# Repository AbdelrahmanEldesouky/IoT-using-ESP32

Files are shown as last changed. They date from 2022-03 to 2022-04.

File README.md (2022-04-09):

# IoT using ESP32 for Home Control 

## Software 

Programming nodeMCU-32S using [Arduino code](Home_Control/Software/HomeControl/HomeControl.ino) to connect with io.adafruit platform using MQTT protocol 

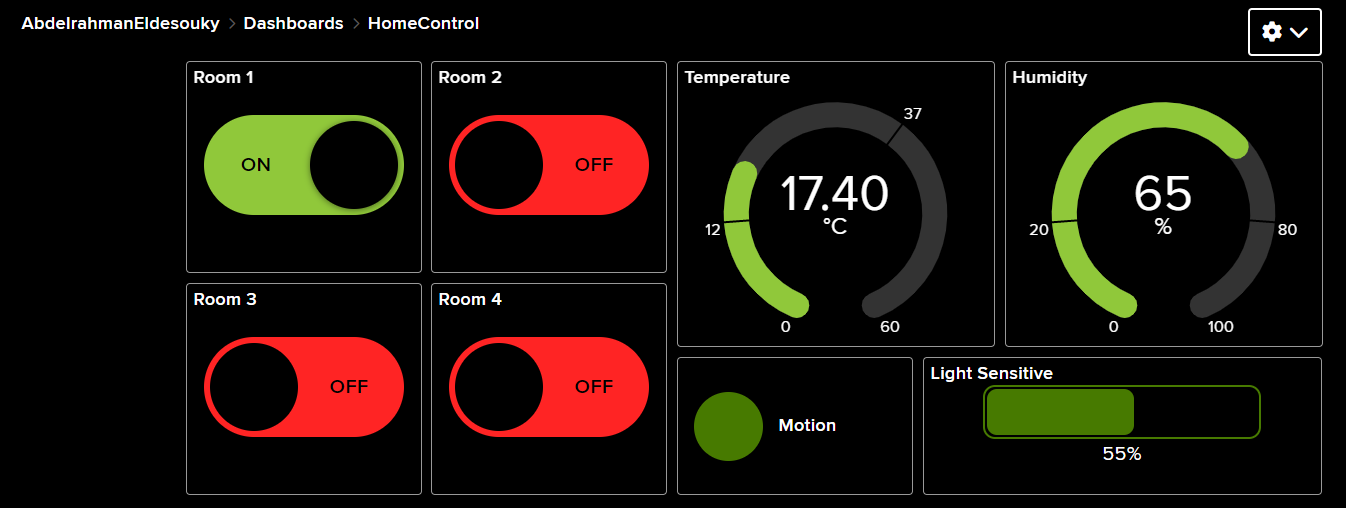
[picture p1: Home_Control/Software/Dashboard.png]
Dashboard


## Hardware

### Component 

1. nodeMCU-ESP32S
2. BT139 
3. MOC3022m 
4. PIR Sensor
5. DHT11 
6. LDR 

Check [data sheet](Home_Control/Hardware/Datasheet) for used components. 

### Schematic 

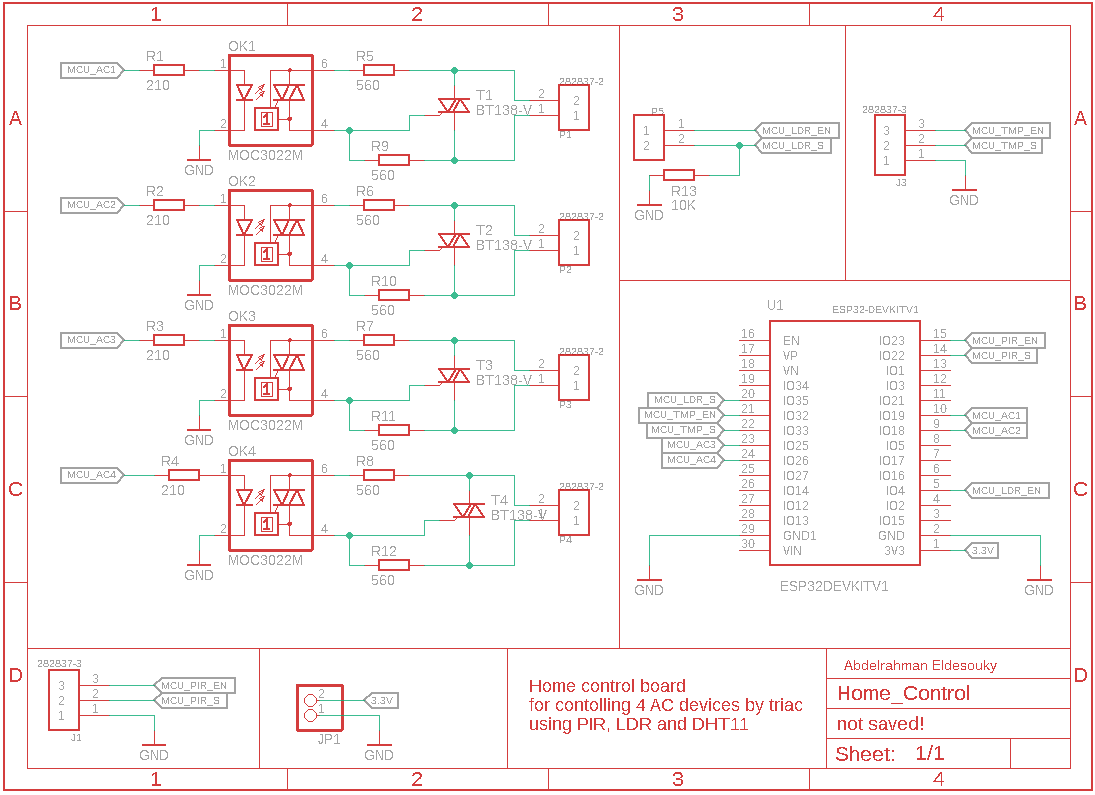
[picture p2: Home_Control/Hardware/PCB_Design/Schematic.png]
Schematic


### Layout 

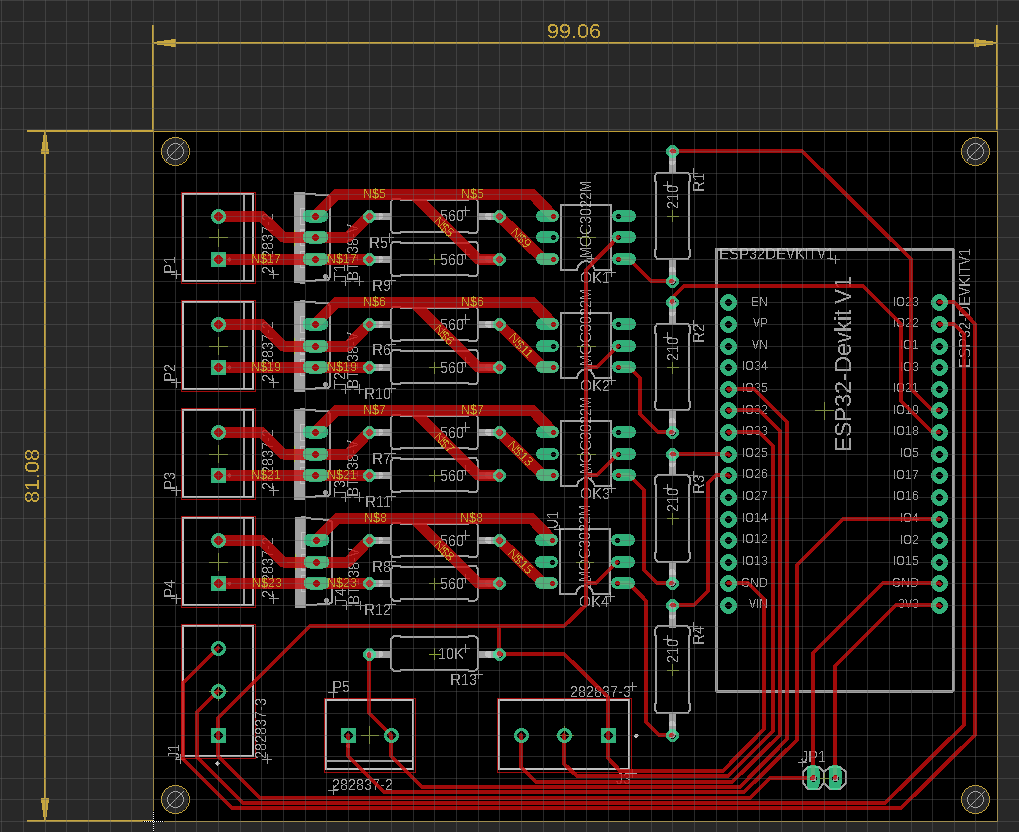
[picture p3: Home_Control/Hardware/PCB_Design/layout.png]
layout


### Prototype

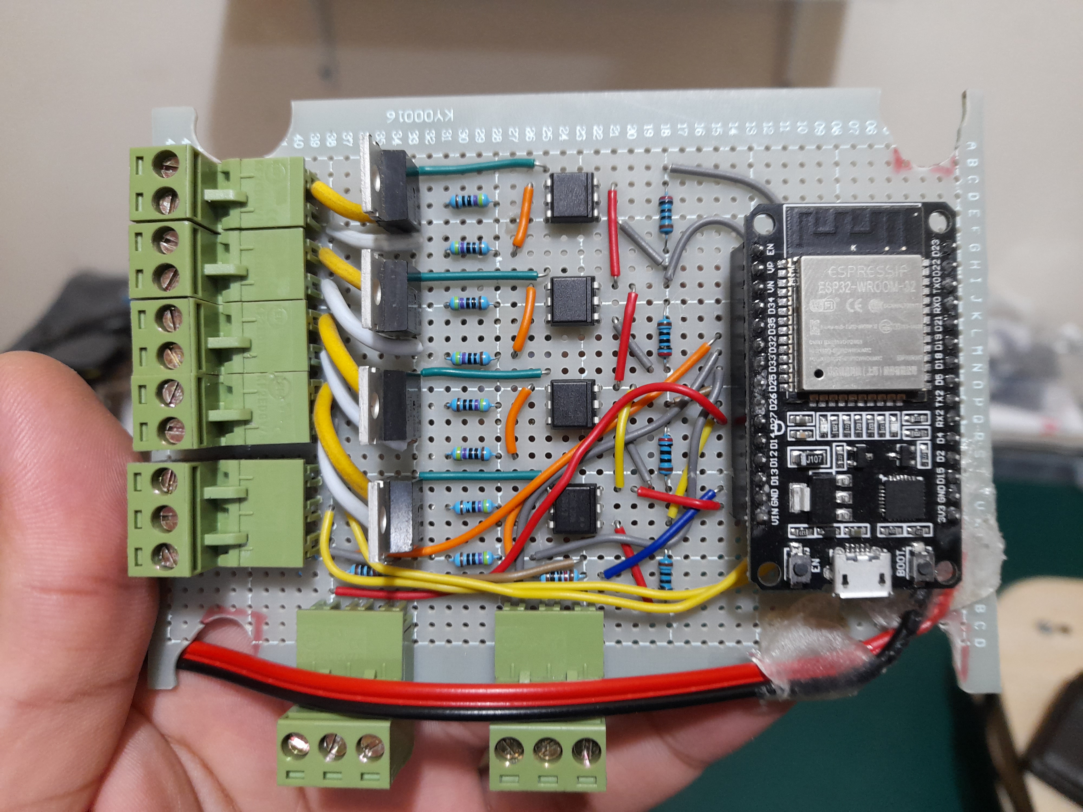
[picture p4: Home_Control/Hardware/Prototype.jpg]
Prototype


### PCB 3D View

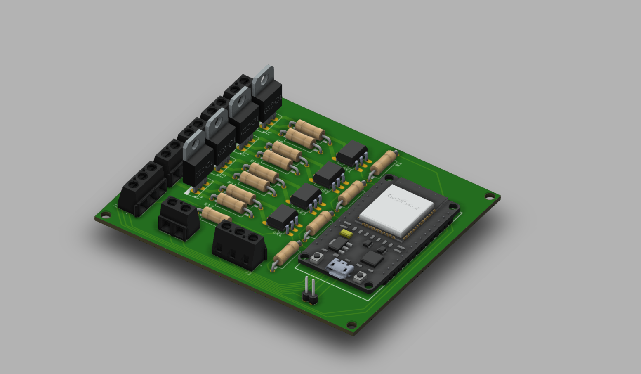
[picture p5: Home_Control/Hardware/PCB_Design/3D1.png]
3D#1


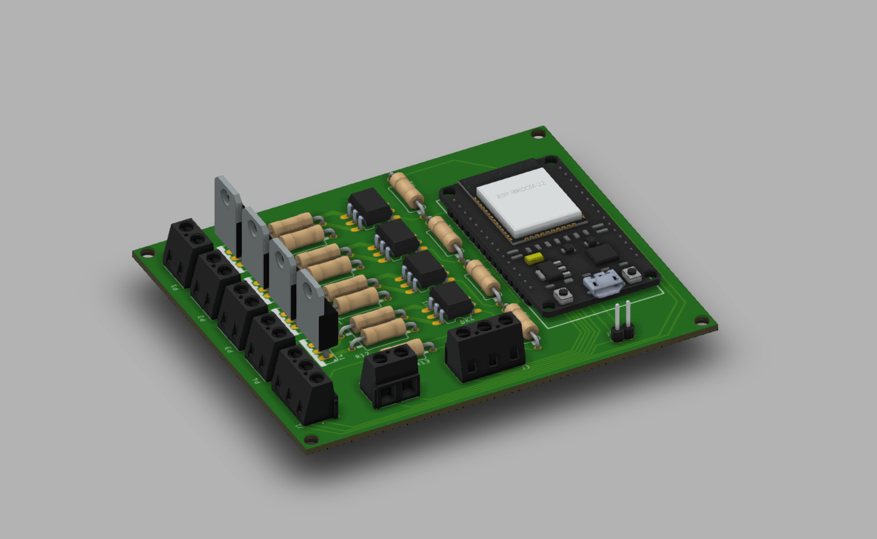
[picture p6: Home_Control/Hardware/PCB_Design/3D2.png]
3D#2


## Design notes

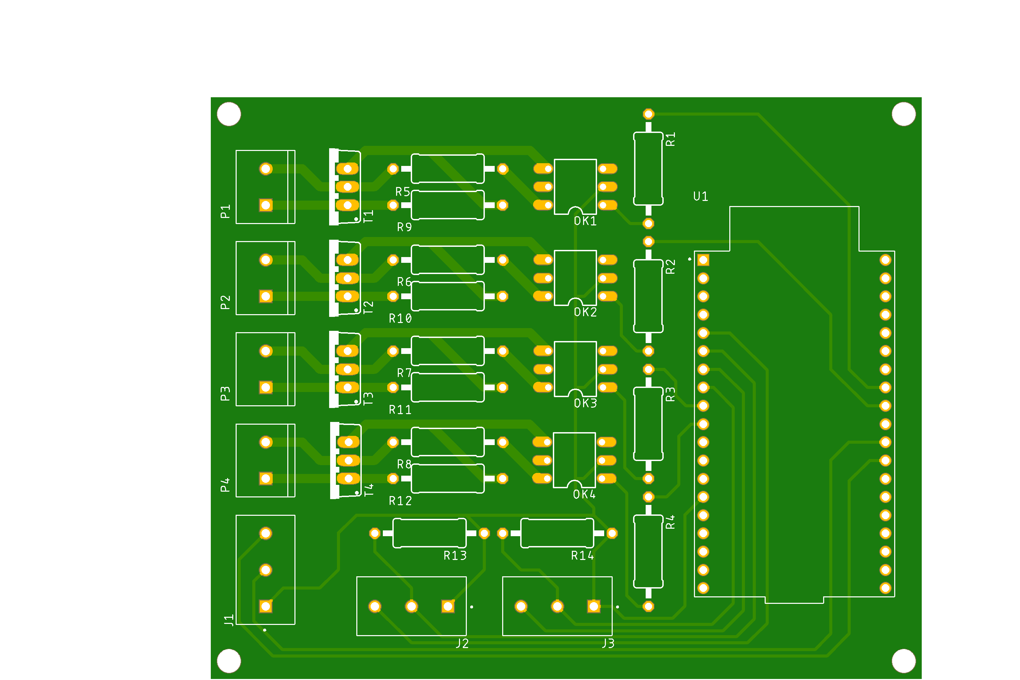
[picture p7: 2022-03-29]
Home_Control/Hardware/PCB_Design/Home_Control.png

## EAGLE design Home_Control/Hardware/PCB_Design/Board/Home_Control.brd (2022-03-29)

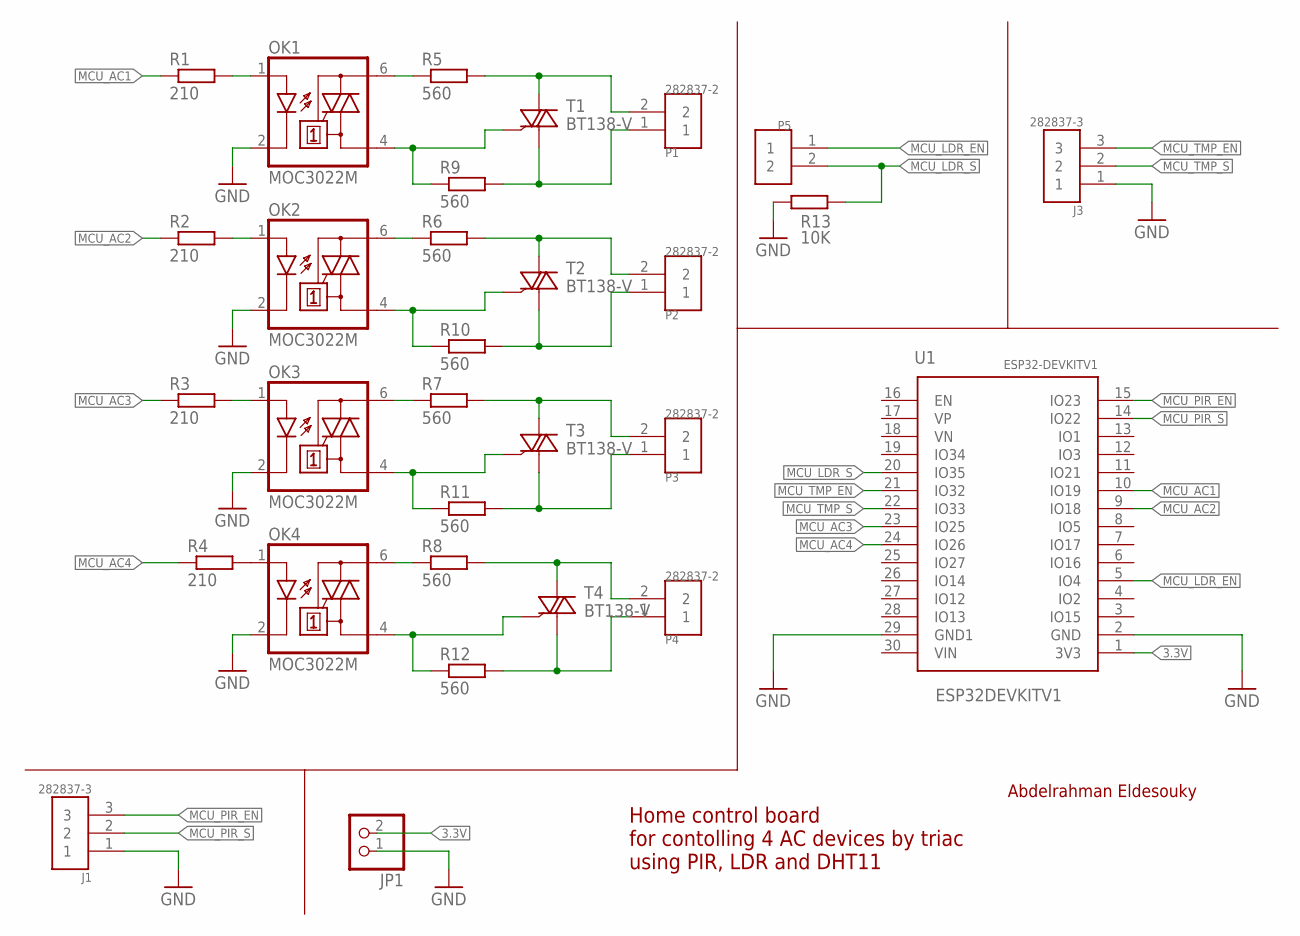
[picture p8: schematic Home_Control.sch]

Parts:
J1, J3: 282837-3; TE_282837-3
JP1: PINHD-1X2; 1X02
OK1, OK2, OK3, OK4: MOC3022M; DIL06
P1, P2, P3, P4, P5: 282837-2; TE_282837-2
R1, R2, R3, R4: 210; 0411/15
R5, R6, R7, R8, R9, R10, R11, R12: 560; 0411/15
R13: 10K; 0411/15
T1, T2, T3, T4: BT138-V; TO220BV
U1: ESP32DEVKITV1; ESP32-DEVKITV1

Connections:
3.3V: JP1.2, U1.1 (3V3)
GND: J1.1, J3.1, JP1.1, OK1.2 (C), OK2.2 (C), OK3.2 (C), OK4.2 (C), R13.1, U1.2 (GND), U1.29 (GND1)
MCU_AC1: R1.1, U1.10 (IO19)
MCU_AC2: R2.1, U1.9 (IO18)
MCU_AC3: R3.1, U1.23 (IO25)
MCU_AC4: R4.1, U1.24 (IO26)
MCU_LDR_EN: P5.1, U1.5 (IO4)
MCU_LDR_S: P5.2, R13.2, U1.20 (IO35)
MCU_PIR_EN: J1.3, U1.15 (IO23)
MCU_PIR_S: J1.2, U1.14 (IO22)
MCU_TMP_EN: J3.3, U1.21 (IO32)
MCU_TMP_S: J3.2, U1.22 (IO33)
unnamed: OK1.1 (A), R1.2
unnamed: OK2.1 (A), R2.2
unnamed: OK3.1 (A), R3.2
unnamed: OK4.1 (A), R4.2
unnamed: OK1.4 (A1), R9.1, T1.G
unnamed: OK2.4 (A1), R10.1, T2.G
unnamed: OK3.4 (A1), R11.1, T3.G
unnamed: OK4.4 (A1), R12.1, T4.G
unnamed: OK1.6 (A2), R5.1
unnamed: P1.2, R5.2, T1.T2 (A2)
unnamed: OK2.6 (A2), R6.1
unnamed: P2.2, R6.2, T2.T2 (A2)
unnamed: OK3.6 (A2), R7.1
unnamed: P3.2, R7.2, T3.T2 (A2)
unnamed: OK4.6 (A2), R8.1
unnamed: P4.2, R8.2, T4.T2 (A2)
unnamed: P1.1, R9.2, T1.T1 (A1)
unnamed: P2.1, R10.2, T2.T1 (A1)
unnamed: P3.1, R11.2, T3.T1 (A1)
unnamed: P4.1, R12.2, T4.T1 (A1)

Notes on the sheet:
Abdelrahman Eldesouky
Home control board for contolling 4 AC devices by triac using PIR, LDR and DHT11

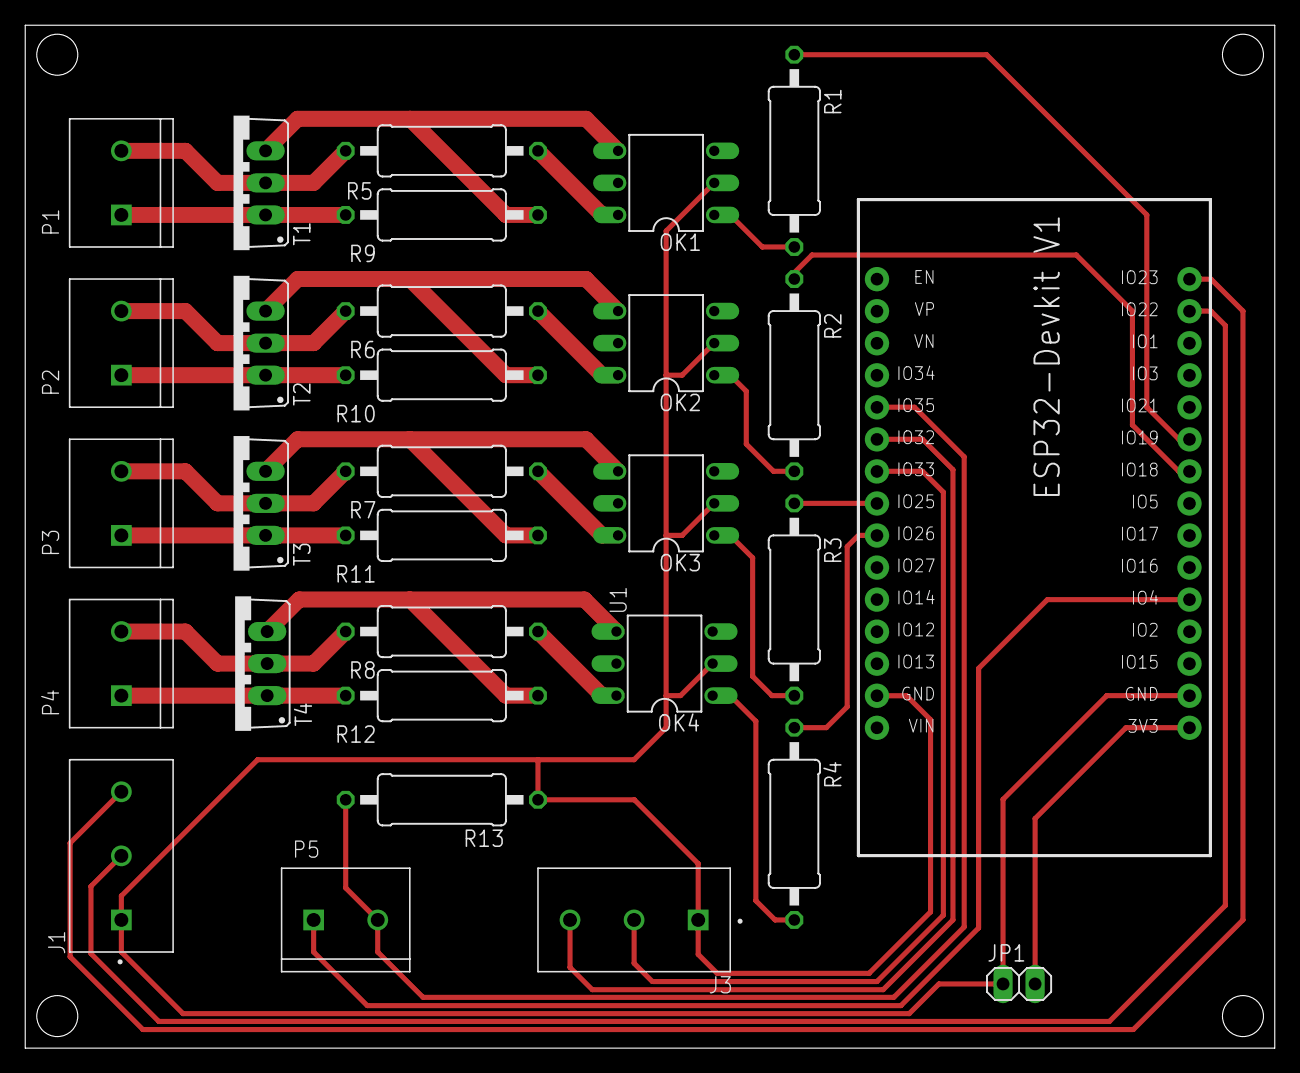
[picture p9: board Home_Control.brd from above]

Board: 2 copper layers, 99.0 x 81.1 mm, 30 parts (0 on the bottom side), 32 nets.

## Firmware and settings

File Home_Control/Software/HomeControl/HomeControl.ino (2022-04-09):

/************************ Include used library ************************/
#include <WiFi.h>
#include "Adafruit_MQTT.h"
#include "Adafruit_MQTT_Client.h"
#include "DHT.h"

/************************ wifi setup ************************/
#define WIFI_SSID       "Desoky"
#define WIFI_PASSWORD   "12345678"

/************************ MQTT setup ************************/
#define IO_SERVER       "io.adafruit.com"
#define IO_SERVERPORT   1883
#define IO_USERNAME     "AbdelrahmanEldesouky"
#define IO_KEY          "aio_gVsC40dHezneCN3UspjPLa8h16u1"

// Setup the MQTT client class by passing in the WiFi client and MQTT server and login details. 
WiFiClient client;
Adafruit_MQTT_Client mqtt(&client, IO_SERVER, IO_SERVERPORT, IO_USERNAME, IO_KEY);
Adafruit_MQTT_Publish TMP = Adafruit_MQTT_Publish(&mqtt, IO_USERNAME "/feeds/TMP");
Adafruit_MQTT_Publish HUM = Adafruit_MQTT_Publish(&mqtt, IO_USERNAME "/feeds/HUM");
Adafruit_MQTT_Publish PIR = Adafruit_MQTT_Publish(&mqtt, IO_USERNAME "/feeds/PIR");
Adafruit_MQTT_Publish LDR = Adafruit_MQTT_Publish(&mqtt, IO_USERNAME "/feeds/LDR");
Adafruit_MQTT_Subscribe AC1 = Adafruit_MQTT_Subscribe(&mqtt, IO_USERNAME "/feeds/AC1", MQTT_QOS_1);
Adafruit_MQTT_Subscribe AC2 = Adafruit_MQTT_Subscribe(&mqtt, IO_USERNAME "/feeds/AC2", MQTT_QOS_1);
Adafruit_MQTT_Subscribe AC3 = Adafruit_MQTT_Subscribe(&mqtt, IO_USERNAME "/feeds/AC3", MQTT_QOS_1);
Adafruit_MQTT_Subscribe AC4 = Adafruit_MQTT_Subscribe(&mqtt, IO_USERNAME "/feeds/AC4", MQTT_QOS_1);


/************************ pin connection ************************/
#define MCU_PIR_EN 23
#define MCU_PIR_S 22
#define MCU_LDR_EN 32
#define MCU_LDR_S 33
#define MCU_TMP_EN 27
#define MCU_TMP_S 13
#define MCU_AC1 19
#define MCU_AC2 18
#define MCU_AC3 25
#define MCU_AC4 26

/************************ DHT11 setup ************************/
#define TMP_TYPE DHT11
DHT dht(MCU_TMP_S, TMP_TYPE);

/************************ Vaiables used ************************/
bool isConnected{false};
bool isMoved{false};
bool isCallBack {false} ; 

long int NOW_t ; 
long int LDR_t ;
long int TMP_t ; 
long int PIR_t ; 

// connect to adafruit io via MQTT
void connect() 
{
  Serial.print(F("Connecting to Adafruit IO... "));
  int8_t ret;
  while ((ret = mqtt.connect()) != 0) 
  {
    switch (ret) 
    {
      case 1: Serial.println(F("Wrong protocol")); break;
      case 2: Serial.println(F("ID rejected")); break;
      case 3: Serial.println(F("Server unavail")); break;
      case 4: Serial.println(F("Bad user/pass")); break;
      case 5: Serial.println(F("Not authed")); break;
      case 6: Serial.println(F("Failed to subscribe")); break;
      default: Serial.println(F("Connection failed")); break;
    }

    if(ret >= 0)
      mqtt.disconnect();

    Serial.println(F("Retrying connection..."));
    delay(10000);
  }
  Serial.println(F("Adafruit IO Connected!"));
}

void read_TMP_HUM()
{
  if ((millis() - TMP_t) > 10000)
  {
    /************************ TMP Sensor ************************/
    // Reading temperature or humidity takes about 250 milliseconds!
    // Sensor readings may also be up to 2 seconds 'old' (its a very slow sensor)
    float h = dht.readHumidity();
    // Read temperature as Celsius (the default)
    float t = dht.readTemperature();
    
    // Check if any reads failed and exit early (to try again).
    if (isnan(h) || isnan(t)) 
    {
      Serial.println(F("Failed to read from DHT sensor!"));
      return;
    }
    
    Serial.print(F("Humidity: "));
    Serial.print(h);
    Serial.print(F("%  Temperature: "));
    Serial.print(t);
    Serial.print(F("°C "));
    
    if (! TMP.publish(t)) //Publish to Adafruit
    {                     
      Serial.println(F("Failed"));
    } 
    if (! HUM.publish(h)) //Publish to Adafruit
    {                     
      Serial.println(F("Failed"));
    }
    else 
    {
      Serial.println(F("Sent!"));
    }

    TMP_t = millis() ;
  }
}
void read_LDR()
{
  /************************ Light Sensor ************************/
  if ((millis() - LDR_t) > 10000)
  {
    // Reading Light Sensor
    double light = ((double)analogRead(MCU_LDR_S)/ 4096.0) * 100.0 ; 
  
    Serial.print(F("Light Percentage: "));
    Serial.print(light);
    Serial.print(F("%  "));
  
    if (! LDR.publish(light)) //Publish to Adafruit
    {                     
      Serial.println(F("Failed"));
    } 
    else 
    {
      Serial.println(F("Sent!"));
    }

    LDR_t = millis() ;
  }
}
void callBack_PIR()
{
  isMoved = true ; 
  isCallBack = true ; 
  PIR_t = millis() ; 
}

void read_PIR()
{
  /************************ Motion Sensor ************************/
  
  if (((millis() - PIR_t) > 3000) && isCallBack)
  {
    Serial.print(F("Motion detected!  "));
    
    if (! PIR.publish(1)) //Publish to Adafruit
    {                     
      Serial.println(F("Failed"));
    } 
    else 
    {
      Serial.println(F("Sent!"));
    }
    
    isCallBack = false ;
  }
  else if (((millis() - PIR_t) > 10000) && isMoved)
  {
    Serial.print(F("Motion stoped...  "));

    if (! PIR.publish(0)) //Publish to Adafruit
    {                     
      Serial.println(F("Failed"));
    } 
    else 
    {
      Serial.println(F("Sent!"));
    }
    
    isMoved = false ;
  }
}

void AC1_callBack(char *data, uint16_t len)
{
  Serial.print("Hey we're in a AC1 callback, the button value is: ");
  Serial.println(data);

  if (*data == '1')
  {
    digitalWrite(MCU_AC1, HIGH); 
  }
  else 
  {
    digitalWrite(MCU_AC1, LOW); 
  }
}

void AC2_callBack(char *data, uint16_t len)
{
  Serial.print("Hey we're in a AC2 callback, the button value is: ");
  Serial.println(data);

  if (*data == '1')
  {
    digitalWrite(MCU_AC2, HIGH); 
  }
  else 
  {
    digitalWrite(MCU_AC2, LOW); 
  }
}

void AC3_callBack(char *data, uint16_t len)
{
  Serial.print("Hey we're in a AC3 callback, the button value is: ");
  Serial.println(data);

  if (*data == '1')
  {
    digitalWrite(MCU_AC3, HIGH); 
  }
  else 
  {
    digitalWrite(MCU_AC3, LOW); 
  }
}

void AC4_callBack(char *data, uint16_t len)
{
  Serial.print("Hey we're in a AC4 callback, the button value is: ");
  Serial.println(data);

  if (*data == '1')
  {
    digitalWrite(MCU_AC4, HIGH); 
  }
  else 
  {
    digitalWrite(MCU_AC4, LOW); 
  }
}

void setup() 
{
  Serial.begin(9600);
  
  pinMode(LED_BUILTIN, OUTPUT);

  WiFi.begin(WIFI_SSID, WIFI_PASSWORD);

  Serial.println("starting");

  while(WiFi.status() != WL_CONNECTED)
  {
    Serial.println(".");
    digitalWrite(LED_BUILTIN, !digitalRead(LED_BUILTIN));
    delay(1000);
    isConnected = false;
  }

  pinMode(MCU_TMP_EN, OUTPUT) ;
  digitalWrite(MCU_TMP_EN, HIGH) ; 
  pinMode(MCU_LDR_EN, OUTPUT) ;
  digitalWrite(MCU_LDR_EN, HIGH) ; 
  pinMode(MCU_PIR_EN, OUTPUT) ;
  digitalWrite(MCU_PIR_EN, HIGH) ;
  pinMode(MCU_PIR_S, INPUT);
  pinMode(MCU_AC1, OUTPUT) ;
  pinMode(MCU_AC2, OUTPUT) ;
  pinMode(MCU_AC3, OUTPUT) ;
  pinMode(MCU_AC4, OUTPUT) ;
  delay (1000);

  // Set motionSensor pin as interrupt, assign interrupt function and set RISING mode
  attachInterrupt(digitalPinToInterrupt(MCU_PIR_S), callBack_PIR, RISING);

  AC1.setCallback(AC1_callBack);
  mqtt.subscribe(&AC1);

  AC2.setCallback(AC2_callBack);
  mqtt.subscribe(&AC2);

  AC3.setCallback(AC3_callBack);
  mqtt.subscribe(&AC3);

  AC4.setCallback(AC4_callBack);
  mqtt.subscribe(&AC4);

  dht.begin();

  LDR_t = millis() ;
  TMP_t = millis() ;  
}

void loop() 
{
  /************************ wifi connection ************************/
  if ((WiFi.status() == WL_CONNECTED) && !isConnected) 
  {
    Serial.println("Connected");
    digitalWrite(LED_BUILTIN, HIGH);
    isConnected = true;

    connect();
  }
  else if (WiFi.status() != WL_CONNECTED)
  {
    Serial.println("reconected...");
    while (WiFi.status() != WL_CONNECTED)
    {
      WiFi.begin(WIFI_SSID, WIFI_PASSWORD);
      Serial.println(".");
      digitalWrite(LED_BUILTIN, !digitalRead(LED_BUILTIN));
      delay(1000);
    }
   isConnected = false;
  }

  /************************ mqtt connection ************************/
  if(! mqtt.ping(3)) 
  {
    // reconnect to adafruit io
    if(! mqtt.connected())
    connect();
  }

  read_TMP_HUM() ;
  read_LDR() ;
  read_PIR() ;
  mqtt.processPackets(1000);
}
